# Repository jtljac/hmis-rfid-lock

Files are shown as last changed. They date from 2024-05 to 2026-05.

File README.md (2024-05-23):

# hmis-locks
A [PlatformIO](https://platformio.org/) program for a electronic locks that are unlocked using a Wiegand based RFID 
scanner and authorises users using a HMIS endpoint.

# Keypad support
Wiegand readers with keypads are supported. You can configure the valid keycode by setting the `enable_keypad_passcode`
option to a numeric string up to 8 numbers long.

When using the keypad, the '*' (star) button will clear (provided it maps to 0x0A), and the '#' (Hashtag) button will
submit (provided it maps to 0x0B).

# Setup
## Platform IO
This application uses [PlatformIO](https://platformio.org/) for dependency management and installation. Installation
instructions for your platform can be found [here](https://platformio.org/install/cli).

## Config
Configuration options have been exposed in [platformio.ini](/platformio.ini) under the `[base_config]` section.

The `WiFi` and `HMIS` options must be configured for your network and HMIS server. 

The `Unlock` and `Auth` options can be configured to suit your needs. 

The `Pins` options should be configured for your ESP, preferably in a separate section that inherits the `[base_config]` 
section (see the `[config_dfrobot_firebeetle2_esp32e]` section for an example of this).

The `Pin Inversions` options should be configured to match your circuit.

A preset environment has been provided for the [FireBeetle 2 ESP32-E](https://wiki.dfrobot.com/FireBeetle_Board_ESP32_E_SKU_DFR0654#target_5)
(my chosen ESP32), you will need to provide your own environment with it's required pin setup if you have a different
ESP32 (we welcome PRs for alternative setups).

## Installation
Run the following to build and upload the project to your ESP32:
```shell
# [your-env] should be one of the configured env sections in platformio.ini
pio run -t upload -e [your-env]
```

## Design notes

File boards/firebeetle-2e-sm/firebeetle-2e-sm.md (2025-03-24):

# Firebeetle ESP32-e Surface Mount Design

Product Page: https://www.dfrobot.com/product-2195.html
Wiki: https://wiki.dfrobot.com/FireBeetle_Board_ESP32_E_SKU_DFR0654

## Image
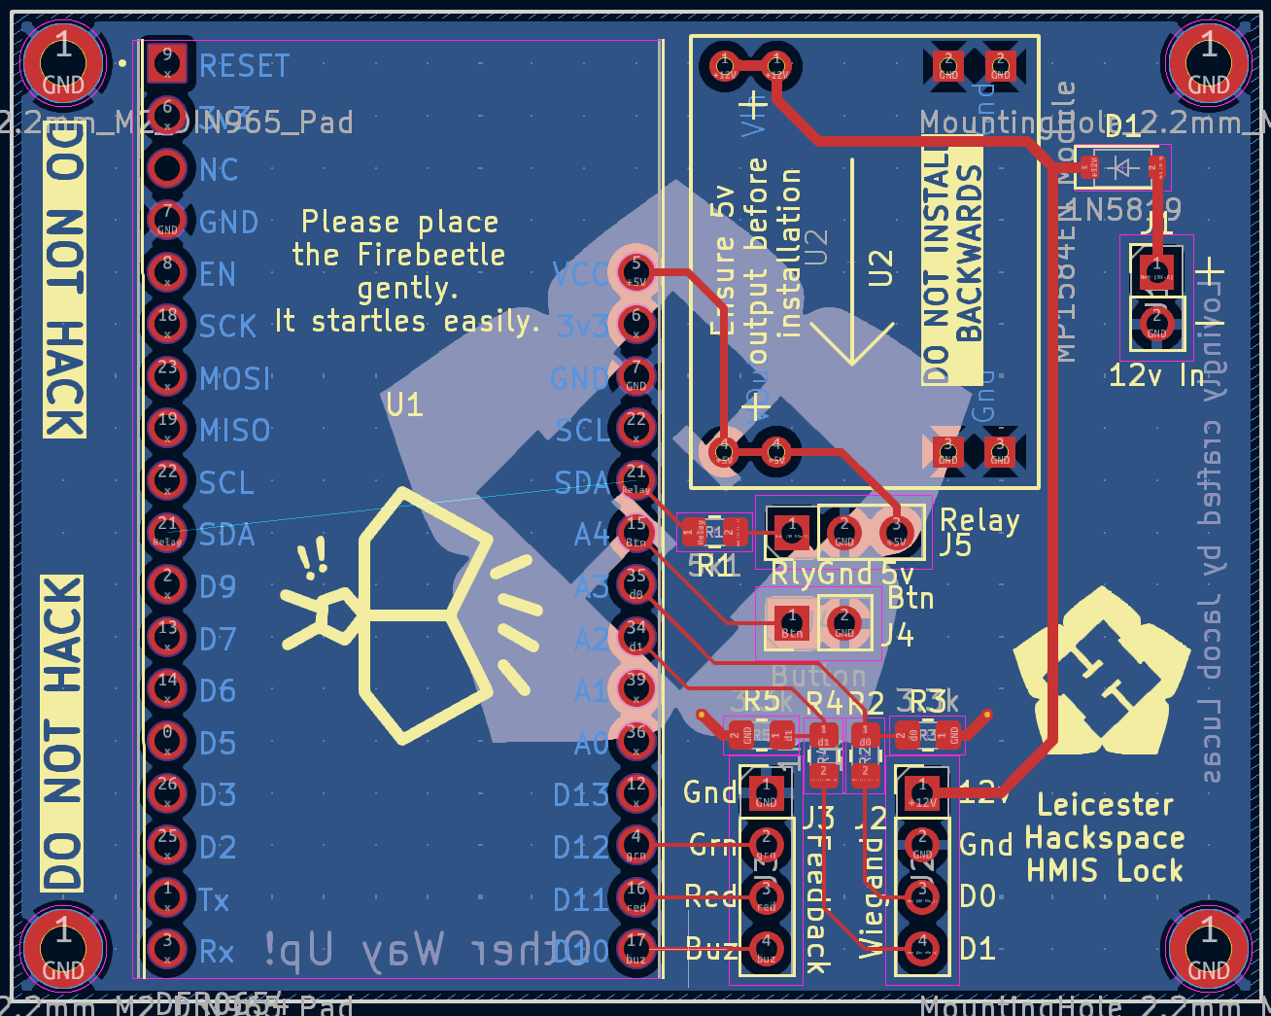
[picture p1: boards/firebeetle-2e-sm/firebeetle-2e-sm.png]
Board screenshot


## Components
- 1x Firebeetle ESP32-e
- 1x [5v relay board](https://www.switchelectronics.co.uk/products/5v-1-channel-low-level-trigger-relay-module-with-optocoupler)
- 1x 12v to 5v buck converter
  - https://kunkune.co.uk/shop/dc-to-dc-converters/small-adjustable-power-supply-step-down-module-mp1584en/
  - https://www.mpja.com/Micro-Adjustable-Step-Down-Buck-DC_DC-Converter-3A/productinfo/35371%20PS/
  - https://www.aliexpress.com/item/1005005870392716.html?spm=a2g0o.order_list.order_list_main.193.254618024ZJA2j
  - https://www.aideepen.com/products/dc-dc-usb-9v-12v-19v-to-5v-3a-step-down-buck-converter-power-supply-charger-module-voltage-regulator-for-vehicle-car-board
- 1x SOD-123 1N5819 Schottkey Diode
- 1x 805 5.1k resistor (Optional for relay)
- 2x 805 1k resistor
- 2x 805 3.3k resistor
- 2x 4x1 2.54mm header
- 1x 3x1 2.54mm header
- 6x 2x1 2.54mm header

## Notes
- The ESP and relay are powered using a 12v to 5v buck converter daughter board
  - None of the boards listed perfectly fit 2.54mm spacing
  - There are a few similar boards that use the MP1584, not all will fit the spacing on the PCB
- The buck converter is expected to be soldered directly to the board.
- The Relay has an optional resistor incase you need to lower the current draw, a 5.1k resistor is suggested for the 
  linked relay.
  - If not using this, you should bridge the gap with solder or a 0 ohm resistor
- A ground pin is provided next to the feedback for when using them to power outputs. When all these pins are inverted
  this ground pin can be ignored.
- A voltage divider is used to step down the Wiegand data lines from 5v to 3v3 to prevent damage to the esp.
  - The voltage divider in particular was used due to protocol being one way, and a logic level shifter being impractical 
    due to the lack of access to the 5v rail at the wiegand side
- The button is using an internal pull-up resistor

## Buck converter modifications (MP2307EN)
The suggested buck converter, MP2307, usually comes with Soft Start enabled, this prevents inrush current when it is 
first powered. However, in this project, this causes the Firebeetle to fail to startup.  
As noted [here](https://forum.arduino.cc/t/esp-is-not-starting-up-first-time-power-is-switched-on/1268814/5), you can 
disable Soft start by removing the capacitor connected to pin 8 of the MP2307 chip:
MP2037EN SS disable

If your MP2038EN Does not match this layout, then you can identify which pin the SS Capacitor connects to with 
[this datasheet](https://cdn-shop.adafruit.com/datasheets/MP2307_r1.9.pdf) and trace that to the capacitor.

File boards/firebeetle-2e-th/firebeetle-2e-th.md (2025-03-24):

# Firebeetle ESP32-e Through Hole Design

Product Page: https://www.dfrobot.com/product-2195.html
Wiki: https://wiki.dfrobot.com/FireBeetle_Board_ESP32_E_SKU_DFR0654

# Image
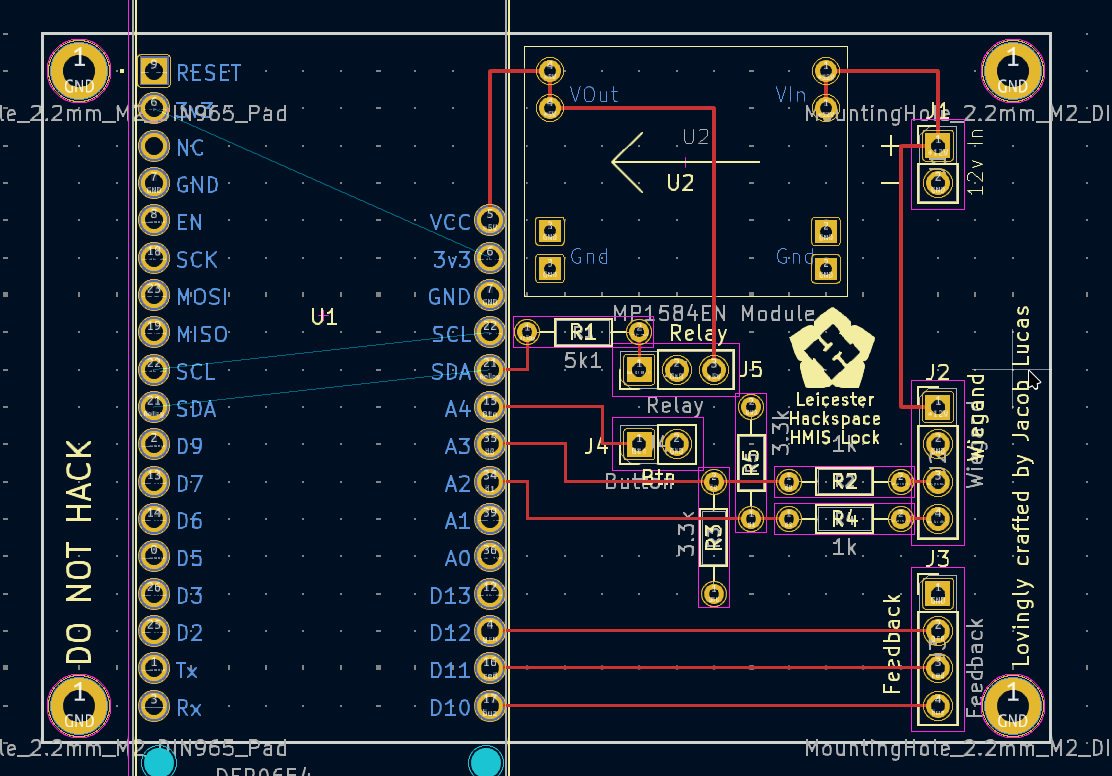
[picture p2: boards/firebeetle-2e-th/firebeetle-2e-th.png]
Board screenshot


# Components
- 1x Firebeetle ESP32-e
- 1x [5v relay board](https://www.switchelectronics.co.uk/products/5v-1-channel-low-level-trigger-relay-module-with-optocoupler)
- 1x [12v to 5v buck converter](https://www.aideepen.com/products/dc-dc-usb-9v-12v-19v-to-5v-3a-step-down-buck-converter-power-supply-charger-module-voltage-regulator-for-vehicle-car-board)
  - https://kunkune.co.uk/shop/dc-to-dc-converters/small-adjustable-power-supply-step-down-module-mp1584en/
  - https://www.mpja.com/Micro-Adjustable-Step-Down-Buck-DC_DC-Converter-3A/productinfo/35371%20PS/
  - https://www.aliexpress.com/item/1005005870392716.html?spm=a2g0o.order_list.order_list_main.193.254618024ZJA2j
  - https://www.aideepen.com/products/dc-dc-usb-9v-12v-19v-to-5v-3a-step-down-buck-converter-power-supply-charger-module-voltage-regulator-for-vehicle-car-board
- 1x 1N5819 Schottkey Diode
- 1x 5.1k resistor (Optional for relay)
- 2x 1k resistor
- 2x 3.3k resistor
- 2x 4x1 2.54mm header
- 1x 3x1 2.54mm header
- 6x 2x1 2.54mm header

# Notes
- The ESP and relay are powered using a 12v to 5v buck converter daughter board
  - None of the boards listed perfectly fit 2.54mm spacing
  - There are a few similar boards that use the MP1584, not all will fit the spacing on the PCB
- The buck converter is expected to be soldered directly to the board.
- The Relay has an optional resistor incase you need to lower the current draw, a 5.1k resistor is suggested for the linked relay.
- A ground pin is provided next to the feedback for when using them to power outputs. When all these pins are inverted
  this ground pin can be ignored.
- A voltage divider is used to step down the Wiegand data lines from 5v to 3v3 to prevent damage to the esp.
  - The voltage divider in particular was used due to protocol being one way, and a logic level shifter being impractical due to the lack of access to the 5v rail at the
    wiegand side
- The button is using an internal pull-up resistor

## Buck converter modifications (MP2307EN)
The suggested buck converter, MP2307, usually comes with Soft Start enabled, this prevents inrush current when it is
first powered. However, in this project, this causes the Firebeetle to fail to startup.  
As noted [here](https://forum.arduino.cc/t/esp-is-not-starting-up-first-time-power-is-switched-on/1268814/5), you can
disable Soft start by removing the capacitor connected to pin 8 of the MP2307 chip:
MP2037EN SS disable

If your MP2038EN Does not match this layout, then you can identify which pin the SS Capacitor connects to with
[this datasheet](https://cdn-shop.adafruit.com/datasheets/MP2307_r1.9.pdf) and trace that to the capacitor.

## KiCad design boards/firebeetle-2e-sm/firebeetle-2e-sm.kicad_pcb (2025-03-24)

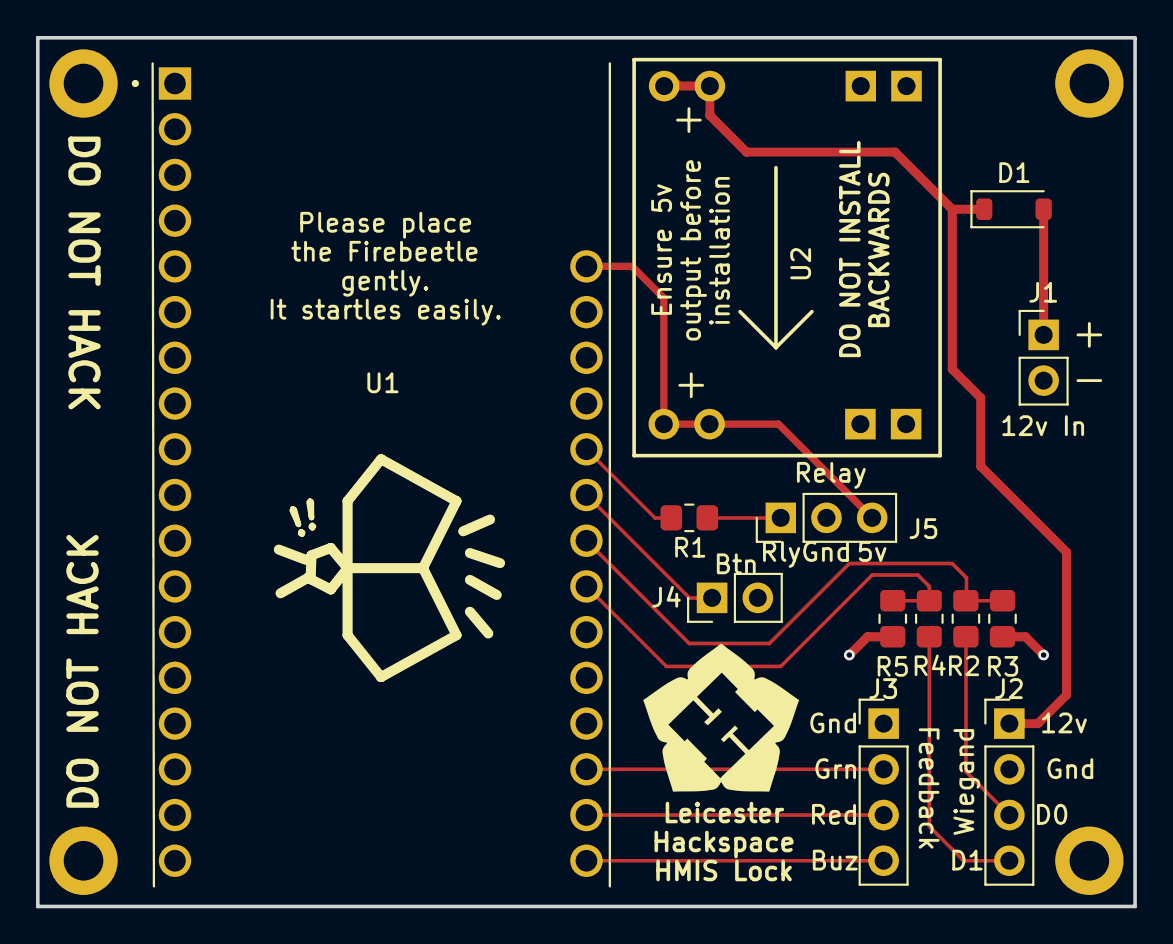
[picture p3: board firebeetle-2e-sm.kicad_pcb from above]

Board: 2 copper layers, 61.0 x 48.3 mm, 17 parts (0 on the bottom side), 14 nets.

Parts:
D1: 1N5819; D_SOD-123
J1: Power In; PinHeader_1x02_P2.54mm_Vertical
J2: Wiegand; PinHeader_1x04_P2.54mm_Vertical
J3: Feedback; PinHeader_1x04_P2.54mm_Vertical
J4: Button; PinHeader_1x02_P2.54mm_Vertical
J5: Relay; PinHeader_1x03_P2.54mm_Vertical
M1, M2, M3, M4: MountingHole_2.2mm_M2_DIN965_Pad
R1: 5k1; R_0805_2012Metric_Pad1.20x1.40mm_HandSolder
R2, R4: 1k; R_0805_2012Metric_Pad1.20x1.40mm_HandSolder
R3, R5: 3.3k; R_0805_2012Metric_Pad1.20x1.40mm_HandSolder
U1: DFR0654; MODULE_DFR0654
U2: MP1584EN Module

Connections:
+5V: J5.3, U1.5 (VCC), U2.4 (VOut)
+12V: D1.1 (K), J2.1, U2.1 (VIn)
/Btn: J4.1, U1.15 (A4)
/Relay: R1.1, U1.21 (SDA)
/buz: J3.4, U1.17 (D10)
/d0: R2.1, R3.2, U1.35 (A3)
/d1: R4.1, R5.1, U1.34 (A2)
/grn: J3.2, U1.4 (D12)
/red: J3.3, U1.16 (D11)
GND: J1.2, J2.2, J3.1, J4.2, J5.2, M1.1, M2.1, M3.1, M4.1, R3.1, R5.2, U1.7 (GND), U2.2 (Gnd), U2.3 (Gnd)
unnamed: D1.2 (A), J1.1
unnamed: J2.3, R2.2
unnamed: J2.4, R4.2
unnamed: J5.1, R1.2

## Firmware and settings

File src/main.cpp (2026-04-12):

#include <Arduino.h>
#include <WiFi.h>

#include "constants.h"
#include "feedback/feedback.h"
#include "authentication/authentication.h"
#include "lock/lock.h"
#include "ota/ota.h"
#include "rfid/rfid.h"

Feedback feedback;
Authentication auth;
Lock lock(feedback);
Ota ota(feedback);
Rfid rfid(feedback);

unsigned long lastBadAuth = 0UL;

/**
 * When either of the Wiegand pins change, update their state in the Rfid instance
 */
void wiegandPinStateChanged() {
    rfid.updatePinState();
}

void setupWifi() {
    WiFi.mode(WIFI_STA);
    WiFi.begin(Constants::wifiSsid, Constants::wifiPass);
    Serial.print(F("Connecting to WiFi Network:"));
    Serial.println(Constants::wifiSsid);

    while(WiFi.status() != WL_CONNECTED) {
        delay(500);
        Serial.print(".");
    }
    Serial.println();
    Serial.print(F("Successfully connected, Local IP: "));
    Serial.println(WiFi.localIP());

    // Enable auto-reconnecting on WiFi loss
    WiFi.setAutoReconnect(true);
    WiFi.persistent(true);
}

void setup() {
    Serial.begin(115200);

    setupWifi();
    auth.setup();
    lock.setup();

    rfid.setup();
    attachInterrupt(digitalPinToInterrupt(Constants::pinD0), wiegandPinStateChanged, CHANGE);
    attachInterrupt(digitalPinToInterrupt(Constants::pinD1), wiegandPinStateChanged, CHANGE);

    ota.setup();
}

void loop() {
    auth.loop();
    rfid.loop();
    lock.loop();
    ota.loop();
    feedback.loop();

    // Check for unlock
    uint32_t nextKey;
    bool hasKey = rfid.getNextKey(&nextKey);
#if ENABLE_KEYPAD_PASSCODE
    uint32_t nextKeycode;
    bool hasPin = rfid.getNextKeyCode(&nextKeycode);
#endif

    unsigned long currentMillis = millis();

    if (currentMillis - lastBadAuth < Constants::badAuthDelay) {
        return;
    }

    // Only handle key if currently locked, otherwise discard
    if (hasKey && lock.isLocked()) {
        if (auth.isAuthorised(nextKey)) {
            Serial.print(F("Read Authorised key: "));
            Serial.println(nextKey, 16);
            lock.unlock();
        } else {
            lastBadAuth = currentMillis;

            Serial.print(F("Read Unauthorised key: "));
            Serial.println(nextKey, 16);

            feedback.unlockLed.blink(Constants::badAuthFlashCount, 100, false);
#if UNLOCK_BUZZ
            feedback.buzzer.blink(5, 100);
#endif
        }
    }
#if ENABLE_KEYPAD_PASSCODE
    if (hasPin && lock.isLocked()) {
        if (nextKeycode == Constants::keycode) {
            Serial.println(F("Keycode Unlock"));
            lock.unlock();
        } else {
            lastBadAuth = currentMillis;

            Serial.print(F("Unauthorised keycode: "));
            Serial.println(nextKeycode, 16);

            feedback.unlockLed.blink(Constants::badAuthFlashCount, 100, false);
#if UNLOCK_BUZZ
            feedback.buzzer.blink(5, 100);
#endif
        }
    }
#endif
}

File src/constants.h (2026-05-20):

#pragma once

#include <WString.h>
#include <Arduino.h>

#define TOSTRINGIMPL(x) #x
#define TOSTRING(x) TOSTRINGIMPL(x)

namespace Constants {
    // General Constants
    /** The amount of time in milliseconds to beep for when locking */
    const int lockBeepTime = 300;

    // Wifi
    /** The SSID of the Wi-Fi network to use */
    const String wifiSsid = F(TOSTRING(WIFI_SSID));
    /** The password of the Wi-Fi network to use */
    const String wifiPass = F(TOSTRING(WIFI_PASS));

    // OTA
    /** The hostname of the ESP for OTA updates */
    const String otaHostname = F(TOSTRING(OTA_HOST));
    /** The password for authenticating OTA updates */
    const String otaPassword = F(TOSTRING(OTA_PASS));

    // HMIS
    /** The ID that represents this Lock in HMIS */
    const String lockId = F(LOCK_ID);
    /** The HMIS URL for fetching a list of authorised RFIDs */
    const String hmisLockUrl = String(HMIS_URL) + "/rfid/lock/" + lockId  + "/";
    /** The HMIS URL for checking if an RFID is authorised */
    const String hmisCheckUrl = String(HMIS_URL) + "/rfid/check/" + lockId  + "/";
    /** The token to authenticate with the HMIS server */
    constexpr char hmisToken[] = TOSTRING(HMIS_TOKEN);
    /** If true, query HMIS directly if a user is authorised, otherwise always check the cache */
    constexpr bool liveCheck = LIVE_CHECK;

    /** The maximum amount of RFIDs to cache (Memory usage is this * 4 bytes) */
    constexpr int maxCachedRfids = 400; // 1.6KiB
    /** The interval in milliseconds between rfid cache updates */
    constexpr unsigned long cacheUpdateInterval = CACHE_UPDATE_INTERVAL * 1000UL; // 30 minutes

    // Lock
    /** The length of time in milliseconds to hold the Lock open for (0 to disable) */
    constexpr unsigned long unlockDelay = UNLOCK_DELAY * 1000;
    /** If true, buzz whilst the door is unlocked */
    constexpr bool unlockBuzz = UNLOCK_BUZZ;
    /**
     * The length of time in milliseconds to block any access attempt (RFID or Keypad) after a failed auth (Bad keycard
     * or Passcode)
     */
    constexpr unsigned long badAuthDelay = BAD_AUTH_DELAY * 1000;
    /**
     * The number of times to flash the LED when an unauthorised input RFID card is scanned, or a bad passcode is
     * entered
     * <p>
     * Each blink is 0.1 seconds, each blink has 2 parts, on then off, therefore to find the number of blinks to cover
     * the full Constants::badAuthDelay, we need to divide the number of seconds to blink for by the length of each
     * blink (0.1 * 2). Constants::badAuthDelay can be 0, so we want to blink atleast 5 times
     */
    const int badAuthFlashCount = max<int>(BAD_AUTH_DELAY / 0.2, 5);
    /** If true, enable entering a keycode using the keypad */
    constexpr bool enableKeycode = ENABLE_KEYPAD_PASSCODE;
    /** The length of the keycode */
    constexpr int keycodeLength = sizeof(KEYPAD_PASSCODE) - 1;
    /** A mask used to clear the unused bits of the keycode */
    constexpr uint32_t keycodeClearMask = 0xFFFFFFFF << keycodeLength * 4;
    /** The keycode packed into a uint32 and correctly masked */
    const uint32_t keycode = keycodeClearMask | strtol(KEYPAD_PASSCODE, nullptr, 16);
    /** If true, the button will unlock the Lock when locked */
    constexpr bool buttonUnlock = BUTTON_UNLOCK;
    /** If true, the button can will lock the Lock when unlocked */
    constexpr bool buttonLock = BUTTON_LOCK;

    /** The number of milliseconds the button must be held for until the button triggers (0 means disabled) */
    constexpr uint32_t buttonHoldTime = BUTTON_HOLD_TIME;

    // Pins
    /** D0 for Wiegand data */
    constexpr int pinD0 = PIN_D0;
    /** D1 for Wiegand Data */
    constexpr int pinD1 = PIN_D1;
    /** Unlocked LED enable (Low to turn on) */
    constexpr int pinLedUnlock = PIN_LED_UNLOCK;
    /** Locked LED enable (Low to turn on) */
    constexpr int pinLedLock = PIN_LED_LOCK;
    /** Buzzer enable (Low to turn on) */
    constexpr int pinBuzzer = PIN_BUZ;
    /** Lock Button observer (Low for pressed) */
    constexpr int pinButtonLock = PIN_BUT_LOCK;
    /** Relay enable (Low to close relay) */
    constexpr int pinRelay = PIN_REL;

    // Pin Inversions
    /** Invert the LED Unlock pin's output so "on" is LOW */
    constexpr bool invertLedUnlock = INVERT_LED_UNLOCK;
    /** Invert the LED Lock pin's output so "on" is LOW */
    constexpr bool invertLedLock = INVERT_LED_LOCK;
    /** Invert the Buzzer pin's output so "on" is LOW */
    constexpr bool invertBuzzer = INVERT_BUZZER;
    /** Invert the Relay pin's output so "on" is LOW */
    constexpr bool invertRelay = INVERT_RELAY;
}

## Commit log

2024-04-28 Terminal Added classes for handling feedback, implemented class for handling the lock, moved RFID handling into own class
    Feedback includes LEDs, buzzers
    [constants.h, internet.cpp, main.cpp]
2024-04-28 Cleanup, documentation, add unlock on correctly scanned keycard
    [constants.h, internet.cpp, main.cpp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]
2024-04-29 Added animations to Output class, fixed incorrect usage of lock and unlock outputs, added flash and tone on failed login
    [constants.h, main.cpp, output.cpp]
2024-04-29 Handle when output changes during an animation, and when a key is scanned whilst currently unlocked
2024-04-29 Add option to check auth with live endpoint, fixed card scanned during unlock being checked after locking
    [constants.h, internet.cpp, main.cpp]
2024-04-29 Improve platformio ini file, improved documentation, changed relay to use output
    Added pin configs that are setup per board in platformio.ini,
    Added URL to platformIO ini,
2024-04-30 Fix bug where lapse in D1 and D0 communication caused panic
    [rfid.cpp]
2024-05-06 Added a configurable delay after failing authorisation to slow brute force attacks
    [constants.h, main.cpp]
2024-05-13 Updated firebeetle pin layout, added board design for firebeetle
    [FireBeetle_ESP32-e.kicad_pcb]
2024-05-15 Fixed misbehaving firebeetle pins, adjusted firebeetle board for new pins
    [FireBeetle_ESP32-e.kicad_pcb]
2024-05-23 Modified board, added pullup setting to button pins, changed http 200 to constant
    [FireBeetle_ESP32-e.kicad_pcb]
2024-08-17 Fixed comments, moved wifi out of class handling auth
    [authentication.cpp, constants.h, main.cpp]
2024-09-13 Updated Board design for Firebeetle
    [FireBeetle_ESP32-e.kicad_pcb]
2025-01-05 Implemented new board, with proper schematic this time
    Went back to voltage divider as the 5v rail from the wiegand wasn't available, nd the protocol is one way anyway
    [FireBeetle_ESP32-e.kicad_pcb, Firebeetle-2e.kicad_pcb, Firebeetle-2e.kicad_sch]
2025-01-07 Fixed issues with firebeetle board
    [Firebeetle-2e.kicad_pcb]
2025-01-21 Updated firebeetle design
    [Firebeetle-2e.kicad_pcb, Firebeetle-2e.kicad_sch]
2025-02-22 Firebeetle EEs
    [Firebeetle-2e.kicad_pcb]
2025-02-26 Created separate through hole and surface mount designs for firebeetle
    [firebeetle-2e-sm.kicad_pcb, firebeetle-2e-sm.kicad_sch, firebeetle-2e-th.kicad_pcb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]
2025-03-06 Addressed design rules for firebeetle surface mount
    [firebeetle-2e-sm.kicad_pcb]
2025-03-21 Added ability to use the button to unlock
2025-03-23 Added 10uF capacitor between reset and ground to handle slow power supply
    [firebeetle-2e-sm.kicad_pcb, firebeetle-2e-sm.kicad_sch]
2025-03-24 Revert EN capacitor, update firebeetle th, updated documentation to remove MP2307EN SS capacitor
    [firebeetle-2e-sm.kicad_pcb, firebeetle-2e-sm.kicad_sch, firebeetle-2e-th.kicad_pcb]
2026-04-12 Added ability to add delay to button press until it triggers the lock
2026-05-20 Add buzzer noise on lock when unlock buzz is disabled
    [constants.h]
